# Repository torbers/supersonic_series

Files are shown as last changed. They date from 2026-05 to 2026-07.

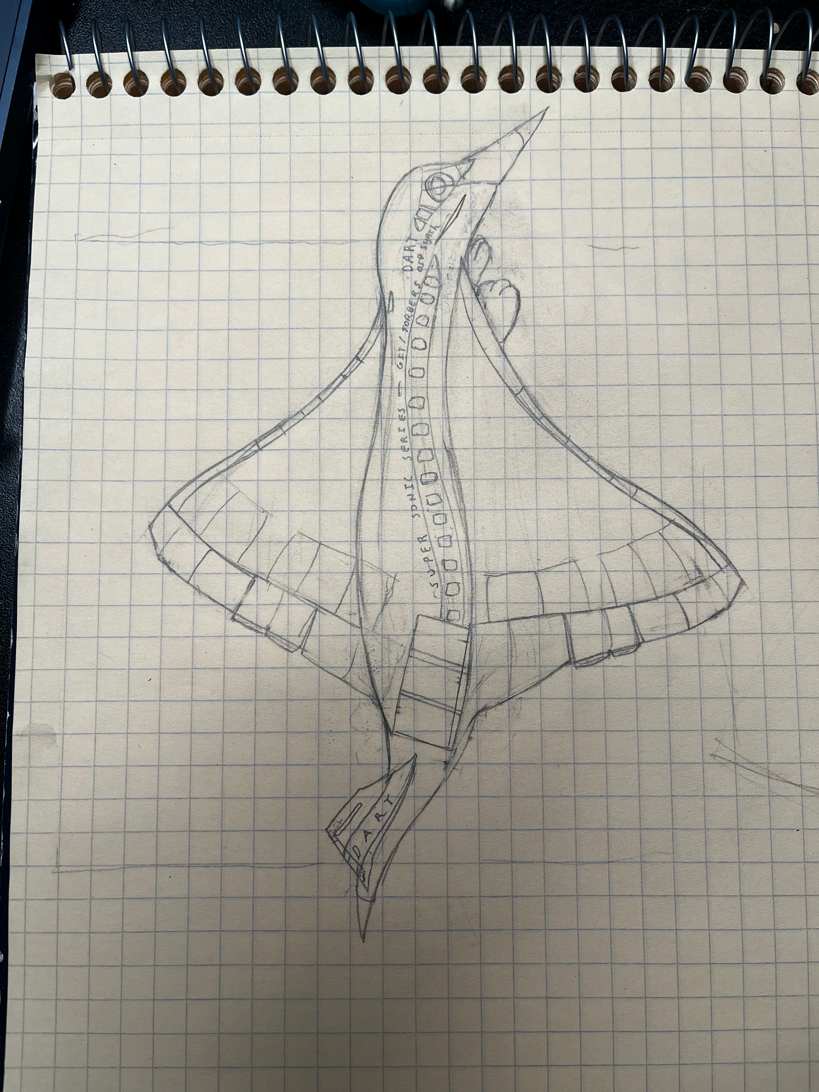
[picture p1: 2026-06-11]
delta/IMG_8657.png

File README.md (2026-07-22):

# Supersonic Series

Airplane dragon synthesizers

## Spike chord synthesizer
### Instruction card


### MIDI CC implementation
| Controller | Effect |
| --- | --- |
| 70 | Chord shape |
| 71 | Filter resonance |
| 72 | Amp envelope attack |
| 73 | Amp envelope release |
| 74 | Filter frequency |
| 75 | Delay time |
| 76 | Delay feedback |
| 77 | Detune |
| 78 | Oscillator bank spread |

### Building Arduino code
The Arduino IDE is the easiest, most portable way to compile and upload code to Spike. This section assumes no previous knowledge of the Arduino IDE in order to accommodate coders of all experience levels.
#### 1. Install Arduino IDE
Follow [this tutorial](https://docs.arduino.cc/software/ide-v2/tutorials/getting-started/ide-v2-downloading-and-installing/) to install the Arduino IDE 2 on your computer. The environment supports Windows, Mac, and Linux.

#### 2. Clone this repository
Use your preferred method to "clone" (download) this repository to your computer. I like the [github desktop app](https://desktop.github.com/download/), but you can also just download the whole thing as a .zip from the [main page](https://github.com/torbers/supersonic_series).

#### 3. Open the file
Once the IDE has installed, choose `File->Open` and navigate to and open `supersonic_series/spike copy/spike_v2_usb/spike_v2_usb.ino`. **Make sure** `spike_v2_usb.ino` and the other files stay in the `spike_v2_usb` folder or it won't open correctly!

#### 4. Install libraries
You will need to install 3 libraries from the built-in library manager (the book icon on the side of the Arduino window).
- **Mozzi** by Tim Barrass: This is our sound synthesis library
- **USB-MIDI** by lathoub: This library sends and recieves MIDI over USB
- **Adafruit_NeoPixel** by Adafruit: This library controls the built in LED

#### 5. Connect Spike
Connect Spike to your computer via the USB C port. **Make sure your cable is capable of data transmission or "sync," and isn't a power-only cable.**
It will appear in Arduino as `Arduino Zero (Native USB)` at the top of the screen. Make sure the text saying this is bold - if so, you're ready to upload.

#### 6. Compile and upload!
Press the arrow button at the top left of the screen to compile and upload the code.

---
## Licensing
All work is shared under [Creative Commons CC BY-SA 4.0](https://creativecommons.org/licenses/by-sa/4.0/): Anyone is free to share, remix, and commercialize it so long as they attribute the work and release it under this same license agreement. (Attribution text modified from [here](https://fullyautomatedrpg.com/licensing/).)

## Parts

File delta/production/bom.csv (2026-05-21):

Designator | Footprint | Quantity | Value | LCSC Part #
LED1, LED2, LED3 | LED-SEG-SMD_10P-L12.0-W7.3-P1.50-BL | 3 | GS3011CR-G | C22462656
U1 | VQFN-20-1EP_3x3mm_P0.4mm_EP1.7x1.7mm | 1 | ATtiny1616-M

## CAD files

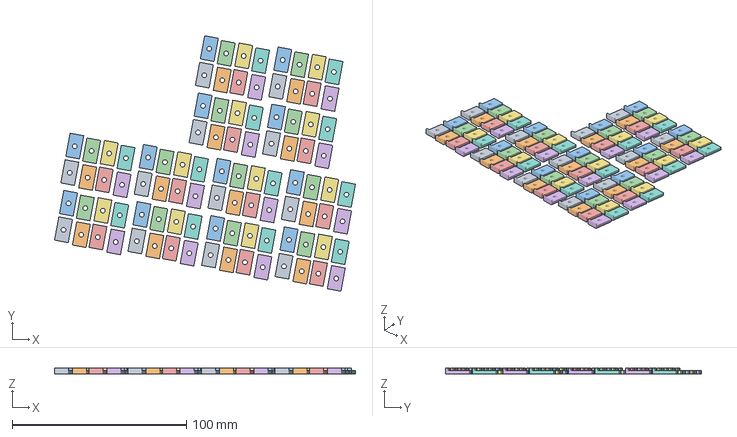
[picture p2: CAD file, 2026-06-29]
clamp2.3mf
172.6 x 146.5 x 3.60 mm
clamp2 x 96

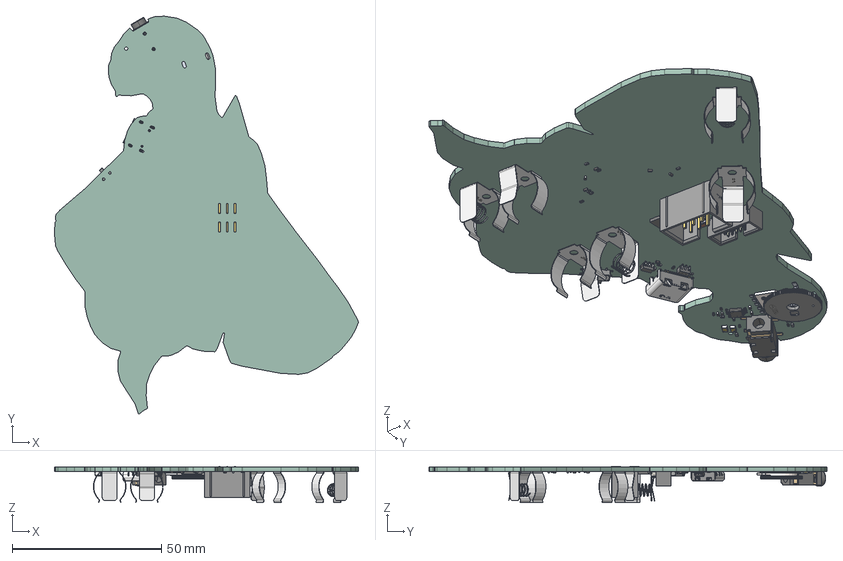
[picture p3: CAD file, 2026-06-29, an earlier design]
spike copy/creature/spike.step
102.0 x 133.4 x 12.1 mm
C_0402_1005Metric x 15
BAT-SMD_MY-AAA-19-J x 3
R_0402_1005Metric x 18
QFN-48-1EP_7x7mm_P0.5mm_EP5.15x5.15mm
IDC-SMD_10P-P1.27-3220-10-0300-00
BAT-SMD_MY-AAA-20-J x 3
SW-SMD_L3.9-W2.9-H2.0-LS4.8
DFN1006-2L-BI x 2
FC-135R_L3.2-W1.5
RES-SMD_RK10J11R0A0H
AUDIO-SMD_PJ-327A5JJ
SOT-23-5
MSOP-10_L3.0-W3.0-H1.1-LS5.0-P0.50
SW-SMD_3P-L6.6-W2.7-LS7.8-P1.50
SOT-23-6_L2.9-W1.6-H1.5-LS2.8-P0.95
USB-C_SMD-TYPE-C-31-M-12_1
C0805_L2.0-W1.3-H1.3 x 4
CONN-SMD_6P-P2.54_BH254VS
creature_PCB

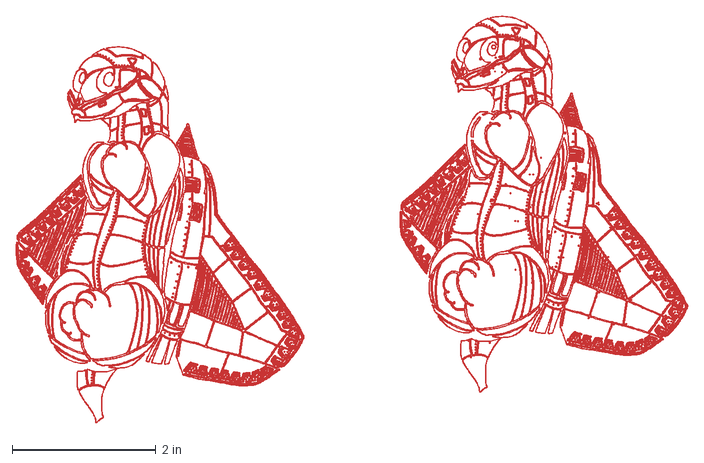
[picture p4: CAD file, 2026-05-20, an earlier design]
spike copy/creature/creature-Front.dxf
9.35 x 5.65 in

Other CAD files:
spike copy/creature/.step

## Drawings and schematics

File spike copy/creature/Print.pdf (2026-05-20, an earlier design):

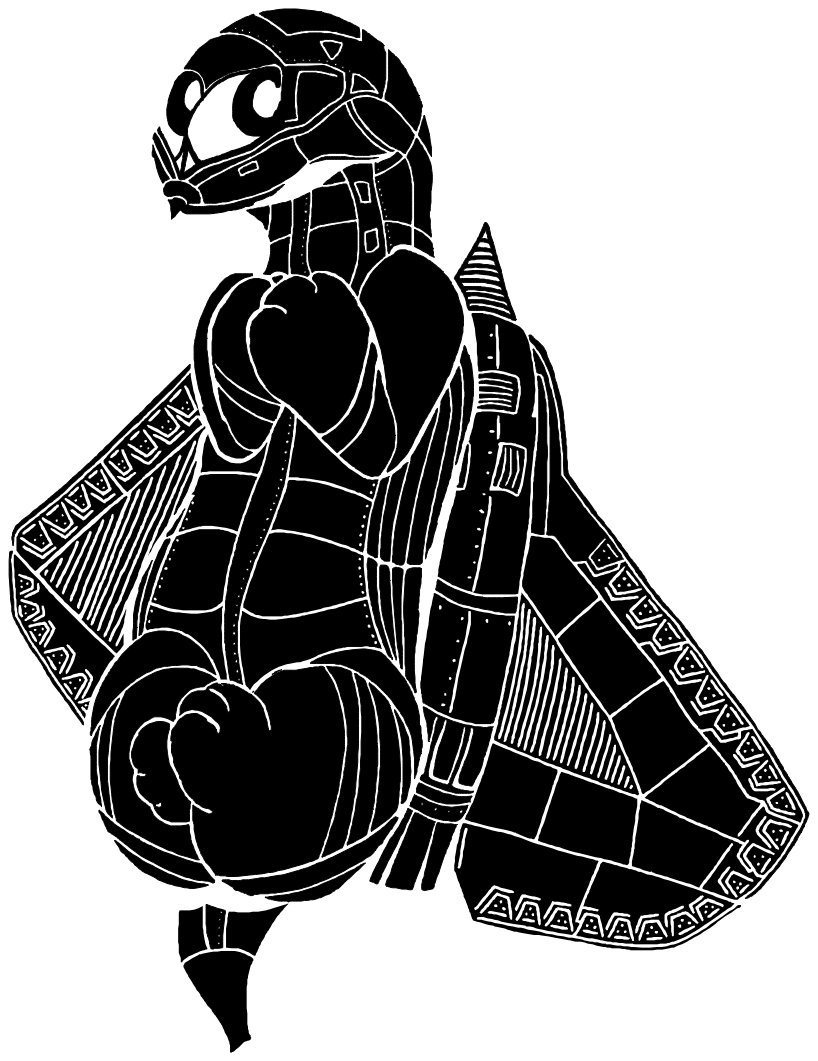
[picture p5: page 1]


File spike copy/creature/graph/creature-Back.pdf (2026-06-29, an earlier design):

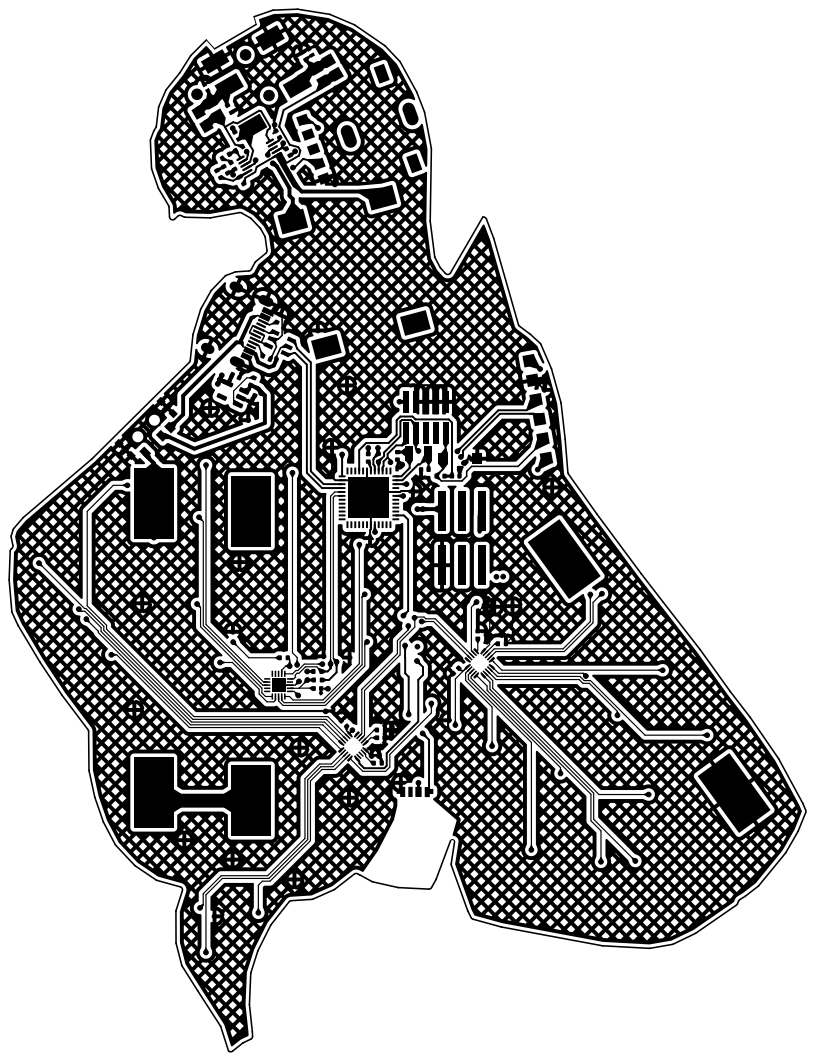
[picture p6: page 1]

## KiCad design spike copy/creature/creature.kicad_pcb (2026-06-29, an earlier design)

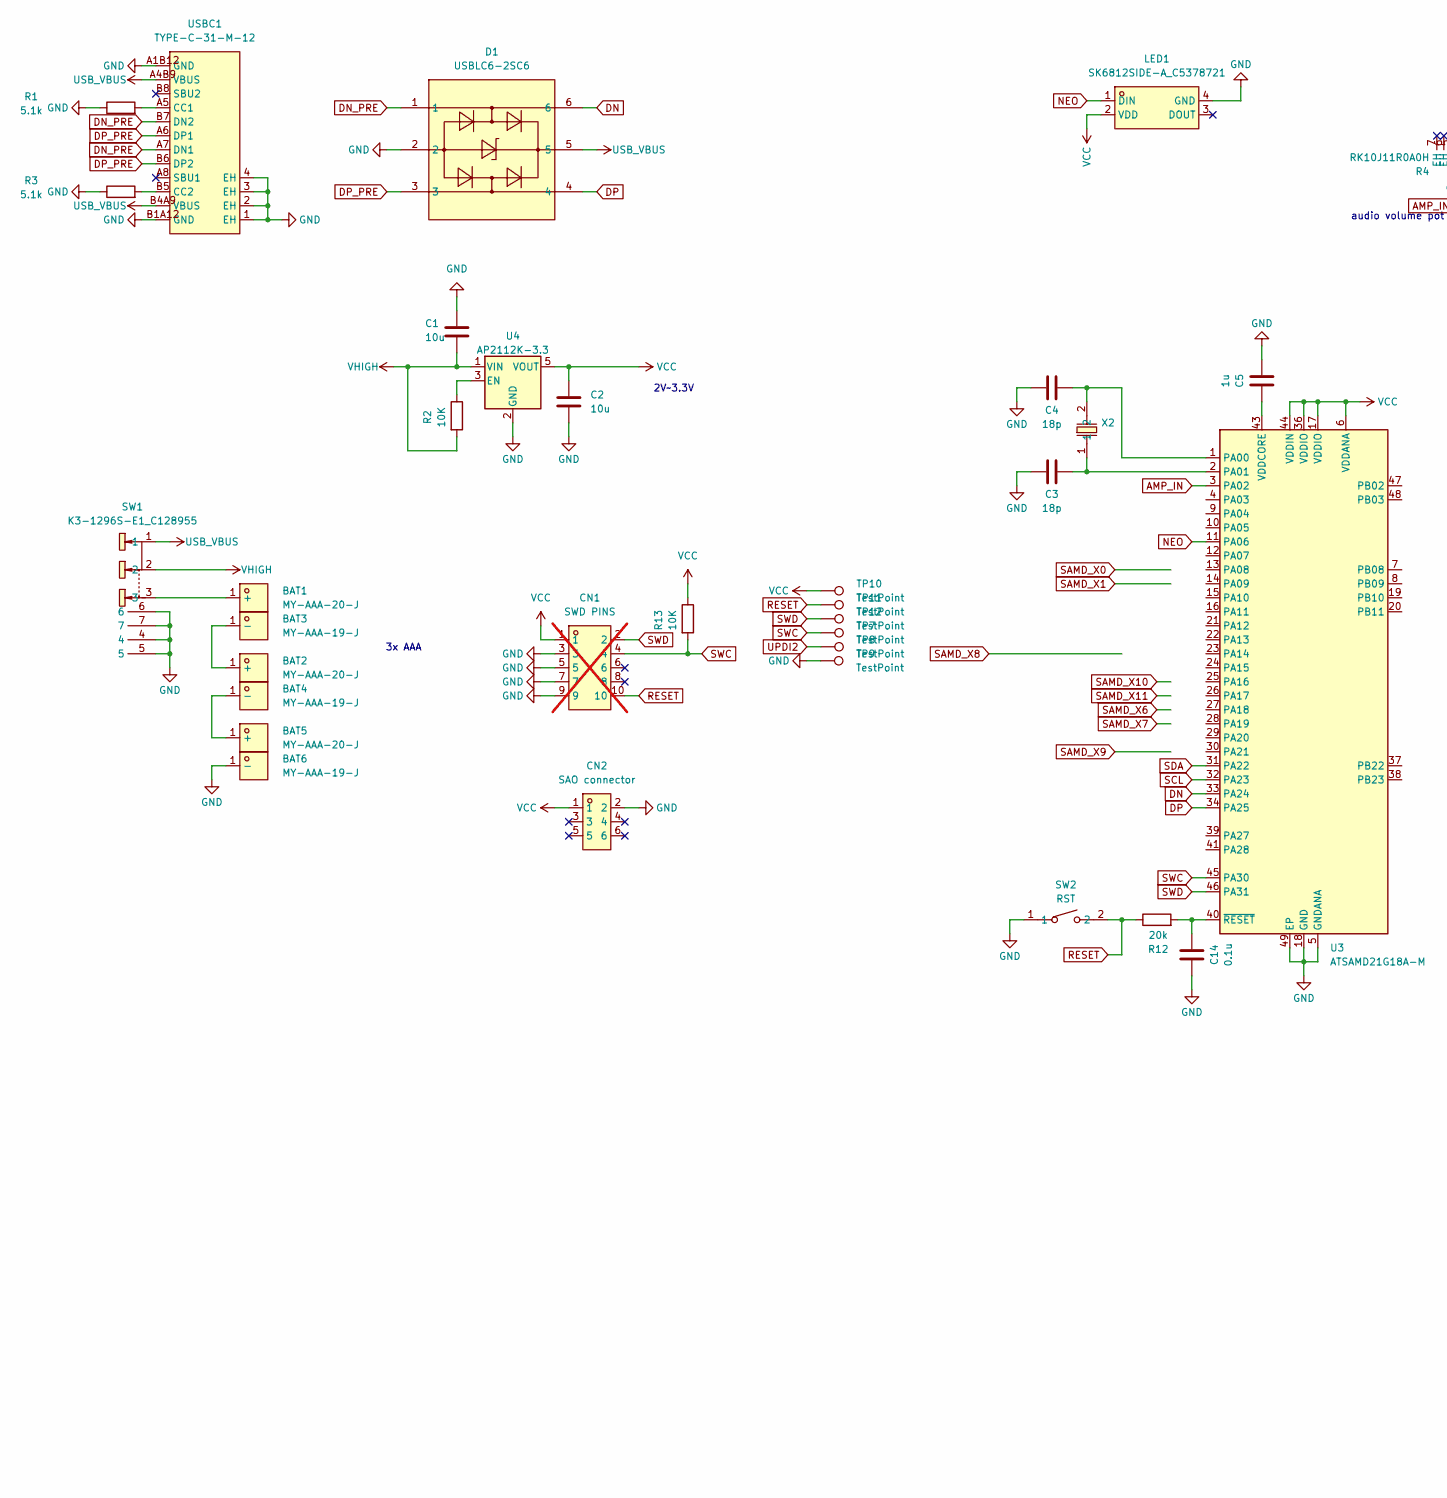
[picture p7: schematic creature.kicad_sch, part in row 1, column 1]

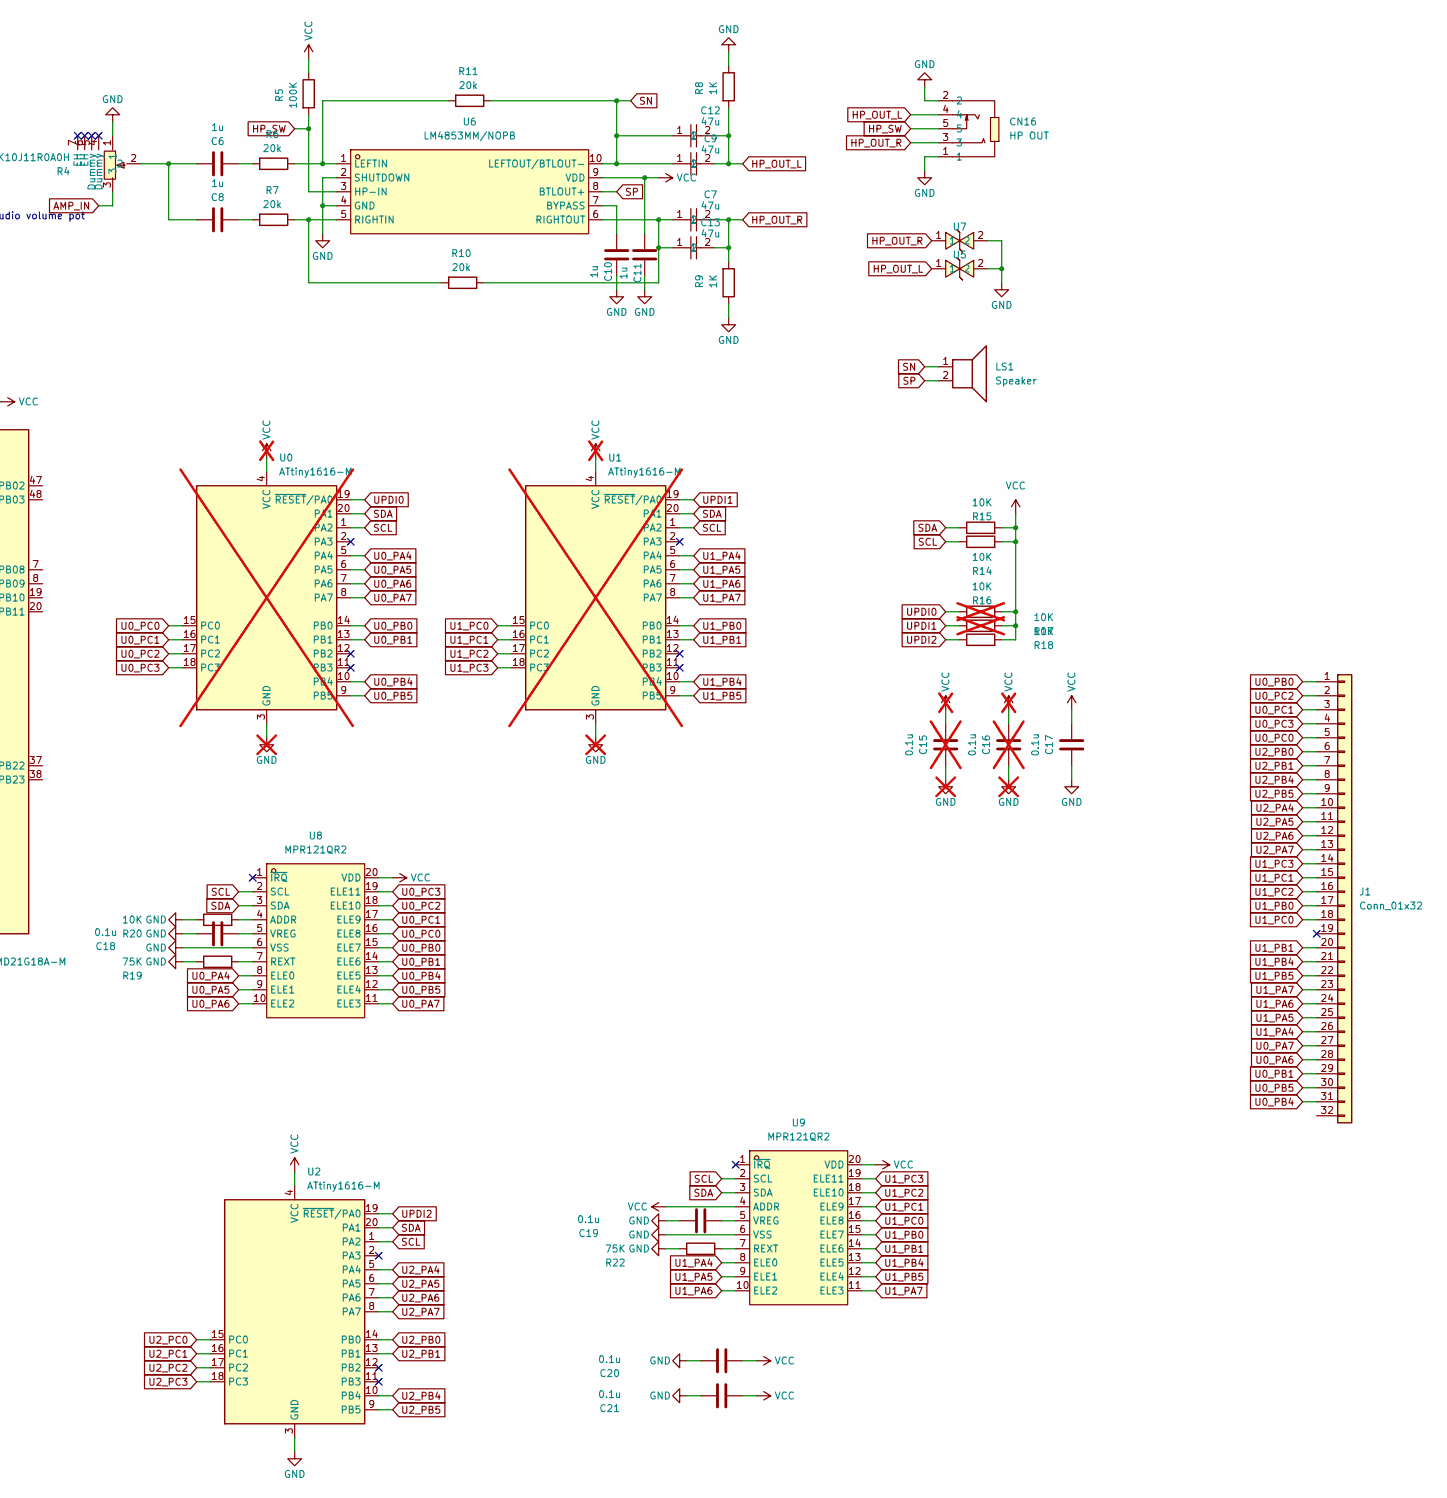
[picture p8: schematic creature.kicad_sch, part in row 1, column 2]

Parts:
BAT1, BAT2, BAT5: MY-AAA-20-J; BAT-SMD_MY-AAA-20-J; MPN MY-AAA-20-J; LCSC Part C6937107
BAT3, BAT4, BAT6: MY-AAA-19-J; BAT-SMD_MY-AAA-19-J; MPN MY-AAA-19-J; LCSC Part C6937104
C1, C2: 10u; C_0402_1005Metric
C3, C4: 18p; C_0402_1005Metric
C5, C6, C8, C10, C11: 1u; C_0402_1005Metric
C7, C9, C12, C13: 47u; C0805; MPN CL21A476MQYNNNE; LCSC Part C16780
C14, C17, C18, C19, C20, C21: 0.1u; C_0402_1005Metric
C15, C16: 0.1u; C_0402_1005Metric; not fitted
CN1: SWD PINS; IDC-SMD_10P-P1.27-3220-10-0300-00; MPN HX JN1.27-2x5 TP H4.9; LCSC Part C42372555; not fitted
CN2: SAO connector; CONN-SMD_6P-P2.54_BH254VS; MPN BH254VS-6P; LCSC Part C492445
CN16: HP OUT; AUDIO-SMD_PJ-327A5JJ; LCSC Part C668605
D1: USBLC6-2SC6; SOT-23-6_L2.9-W1.6-P0.95-LS2.8-BL; LCSC Part C7519
J1: Conn_01x32; spike_copper
LED1: SK6812SIDE-A_C5378721; LED-SMD_4P-L4.0-W1.6-L; LCSC Part C5378721
LS1: Speaker; FS1818MS0410-H5.9-R01
R1, R3: 5.1k; R_0402_1005Metric
R2, R13, R14, R15, R18, R20: 10K; R_0402_1005Metric
R4: RK10J11R0A0H; RES-SMD_RK10J11R0A0H; MPN RK10J11R0A0H; LCSC Part C470766
R5: 100K; R_0402_1005Metric
R6, R7, R10, R11, R12: 20k; R_0402_1005Metric
R8, R9: 1K; R_0402_1005Metric
R16, R17: 10K; R_0402_1005Metric; not fitted
R19, R22: 75K; R_0402_1005Metric
SW1: K3-1296S-E1_C128955; SW-TH_K3-1296S-E1; MPN K3-1296S-E1; LCSC Part C128955
SW2: RST; SW-SMD_L3.9-W3.0-P4.45; LCSC Part C720477
TP7, TP8, TP9, TP10, TP11, TP12: TestPoint; TestPoint_Pad_1.5x1.5mm
U0, U1: ATtiny1616-M; VQFN-20-1EP_3x3mm_P0.4mm_EP1.7x1.7mm; not fitted
U2: ATtiny1616-M; VQFN-20-1EP_3x3mm_P0.4mm_EP1.7x1.7mm
U3: ATSAMD21G18A-M; QFN-48-1EP_7x7mm_P0.5mm_EP5.15x5.15mm
U4: AP2112K-3.3; SOT-23-5
U5, U7: H3V3U10B; DFN1006-2L-BI; LCSC Part C20615782
U6: LM4853MM/NOPB; MSOP-10_L3.0-W3.0-P0.50-LS4.9-BL; MPN LM4853MM/NOPB; LCSC Part C2872995
U8, U9: MPR121QR2; QFN-20_L3.0-W3.0-P0.40-BL; LCSC Part C91322
USBC1: TYPE-C-31-M-12; USB-C_SMD-TYPE-C-31-M-12_1; LCSC Part C165948
X2: Q13FC1350000400; FC-135R_L3.2-W1.5; MPN Q13FC13500004; LCSC Part C32346

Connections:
AMP_IN: R4.3, U3.3 (PA02)
DN: D1.6, U3.33 (PA24)
DN_PRE: D1.1, USBC1.A7 (DN1), USBC1.B7 (DN2)
DP: D1.4, U3.34 (PA25)
DP_PRE: D1.3, USBC1.A6 (DP1), USBC1.B6 (DP2)
GND: BAT6.1 (-_1), C1.2, C2.2, C3.1, C4.1, C5.1, C10.2, C11.2, C14.1, C15.2, C16.2, C17.2, C18.2, C19.2, C20.2, C21.2, CN1.3, CN1.5, CN1.7, CN1.9, CN2.2, CN16.1, CN16.2, D1.2, LED1.4 (GND), R1.1, R3.1, R4.1, R8.1, R9.1, R19.1, R20.1, R22.1, SW1.4, SW1.5, SW1.6, SW1.7, SW2.1, TP9.1 (1_1), U0.3 (GND), U0.21 (GND), U1.3 (GND), U1.21 (GND), U2.3 (GND), U2.21 (GND), U3.5 (GNDANA), U3.18 (GND), U3.35 (GND), U3.42 (GND), U3.49 (EP), U4.2 (GND), U5.2, U6.2 (SHUTDOWN), U6.4 (GND), U7.2, U8.6 (VSS), U9.6 (VSS), USBC1.1 (EH), USBC1.2 (EH), USBC1.3 (EH), USBC1.4 (EH), USBC1.A1B12 (GND), USBC1.B1A12 (GND)
HP_OUT_L: C9.2, C12.2, CN16.4, R8.2, U5.1
HP_OUT_R: C7.2, C13.2, CN16.3, R9.2, U7.1
HP_SW: CN16.5, R5.2, U6.3 (HP-IN)
NEO: LED1.1 (DIN), U3.11 (PA06)
unnamed: BAT1.1 (+_1), SW1.3
unnamed: BAT2.1 (+_1), BAT3.1 (-_1)
unnamed: BAT4.1 (-_1), BAT5.1 (+_1)
unnamed: C6.1, R6.2
unnamed: C6.2, C8.2, R4.2
unnamed: C8.1, R7.2
unnamed: R16.1, U0.19 (~RESET/PA0)
unnamed: R17.1, U1.19 (~RESET/PA0)
unnamed: C4.2, U3.1 (PA00), X2.2
unnamed: C3.2, U3.2 (PA01), X2.1
unnamed: C5.2, U3.43 (VDDCORE)
unnamed: C14.2, R12.2, U3.40 (~RESET)
unnamed: R2.1, U4.3 (EN)
unnamed: C10.1, U6.7 (BYPASS)
unnamed: R6.1, R11.2, U6.1 (LEFTIN)
unnamed: R7.1, R10.2, U6.5 (RIGHTIN)
unnamed: C7.1, C13.1, R10.1, U6.6 (RIGHTOUT)
unnamed: R20.2, U8.4 (ADDR)
unnamed: R19.2, U8.7 (REXT)
unnamed: C18.1, U8.5 (VREG)
unnamed: R22.2, U9.7 (REXT)
unnamed: C19.1, U9.5 (VREG)
unnamed: R1.2, USBC1.A5 (CC1)
unnamed: R3.2, USBC1.B5 (CC2)
RESET: CN1.10, R12.1, SW2.2, TP11.1 (1_1)
SCL: R14.1, U0.1 (PA2), U1.1 (PA2), U2.1 (PA2), U3.32 (PA23), U8.2 (SCL), U9.2 (SCL)
SDA: R15.1, U0.20 (PA1), U1.20 (PA1), U2.20 (PA1), U3.31 (PA22), U8.3 (SDA), U9.3 (SDA)
SN: C9.1, C12.1, LS1.1, R11.1, U6.10 (LEFTOUT/BTLOUT-)
SP: LS1.2, U6.8 (BTLOUT+)
SWC: CN1.4, R13.2, TP7.1 (1_1), U3.45 (PA30)
SWD: CN1.2, TP12.1 (1_1), U3.46 (PA31)
U0_PA4: U0.5 (PA4), U8.8 (ELE0)
U0_PA5: U0.6 (PA5), U8.9 (ELE1)
U0_PA6: J1.28, U0.7 (PA6), U8.10 (ELE2)
U0_PA7: J1.27, U0.8 (PA7), U8.11 (ELE3)
U0_PB0: J1.1, U0.14 (PB0), U8.15 (ELE7)
U0_PB1: J1.29, U0.13 (PB1), U8.14 (ELE6)
U0_PB4: J1.31, U0.10 (PB4), U8.13 (ELE5)
U0_PB5: J1.30, U0.9 (PB5), U8.12 (ELE4)
U0_PC0: J1.5, U0.15 (PC0), U8.16 (ELE8)
U0_PC1: J1.3, U0.16 (PC1), U8.17 (ELE9)
U0_PC2: J1.2, U0.17 (PC2), U8.18 (ELE10)
U0_PC3: J1.4, U0.18 (PC3), U8.19 (ELE11)
U1_PA4: J1.26, U1.5 (PA4), U9.8 (ELE0)
U1_PA5: J1.25, U1.6 (PA5), U9.9 (ELE1)
U1_PA6: J1.24, U1.7 (PA6), U9.10 (ELE2)
U1_PA7: J1.23, U1.8 (PA7), U9.11 (ELE3)
U1_PB0: J1.17, U1.14 (PB0), U9.15 (ELE7)
U1_PB1: J1.20, U1.13 (PB1), U9.14 (ELE6)
U1_PB4: J1.21, U1.10 (PB4), U9.13 (ELE5)
U1_PB5: J1.22, U1.9 (PB5), U9.12 (ELE4)
U1_PC0: J1.18, U1.15 (PC0), U9.16 (ELE8)
U1_PC1: J1.15, U1.16 (PC1), U9.17 (ELE9)
U1_PC2: J1.16, U1.17 (PC2), U9.18 (ELE10)
U1_PC3: J1.14, U1.18 (PC3), U9.19 (ELE11)
U2_PA4: J1.10, U2.5 (PA4)
U2_PA5: J1.11, U2.6 (PA5)
U2_PA6: J1.12, U2.7 (PA6)
U2_PA7: J1.13, U2.8 (PA7)
U2_PB0: J1.6, U2.14 (PB0)
U2_PB1: J1.7, U2.13 (PB1)
U2_PB4: J1.8, U2.10 (PB4)
U2_PB5: J1.9, U2.9 (PB5)
U2_PC0: U2.15 (PC0)
U2_PC1: U2.16 (PC1)
U2_PC2: U2.17 (PC2)
U2_PC3: U2.18 (PC3)
UPDI2: R18.1, TP8.1 (1_1), U2.19 (~RESET/PA0)
USB_VBUS: D1.5, SW1.1, USBC1.A4B9 (VBUS), USBC1.B4A9 (VBUS)
VCC: C2.1, C11.1, C15.1, C16.1, C17.1, C20.1, C21.1, CN1.1, CN2.1, LED1.2 (VDD), R5.1, R13.1, R14.2, R15.2, R16.2, R17.2, R18.2, TP10.1 (1_1), U0.4 (VCC), U1.4 (VCC), U2.4 (VCC), U3.6 (VDDANA), U3.17 (VDDIO), U3.36 (VDDIO), U3.44 (VDDIN), U4.5 (VOUT), U6.9 (VDD), U8.20 (VDD), U9.4 (ADDR), U9.20 (VDD)
VHIGH: C1.1, R2.2, SW1.2, U4.1 (VIN)

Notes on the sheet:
3x AAA
audio volume pot
2V~3.3V

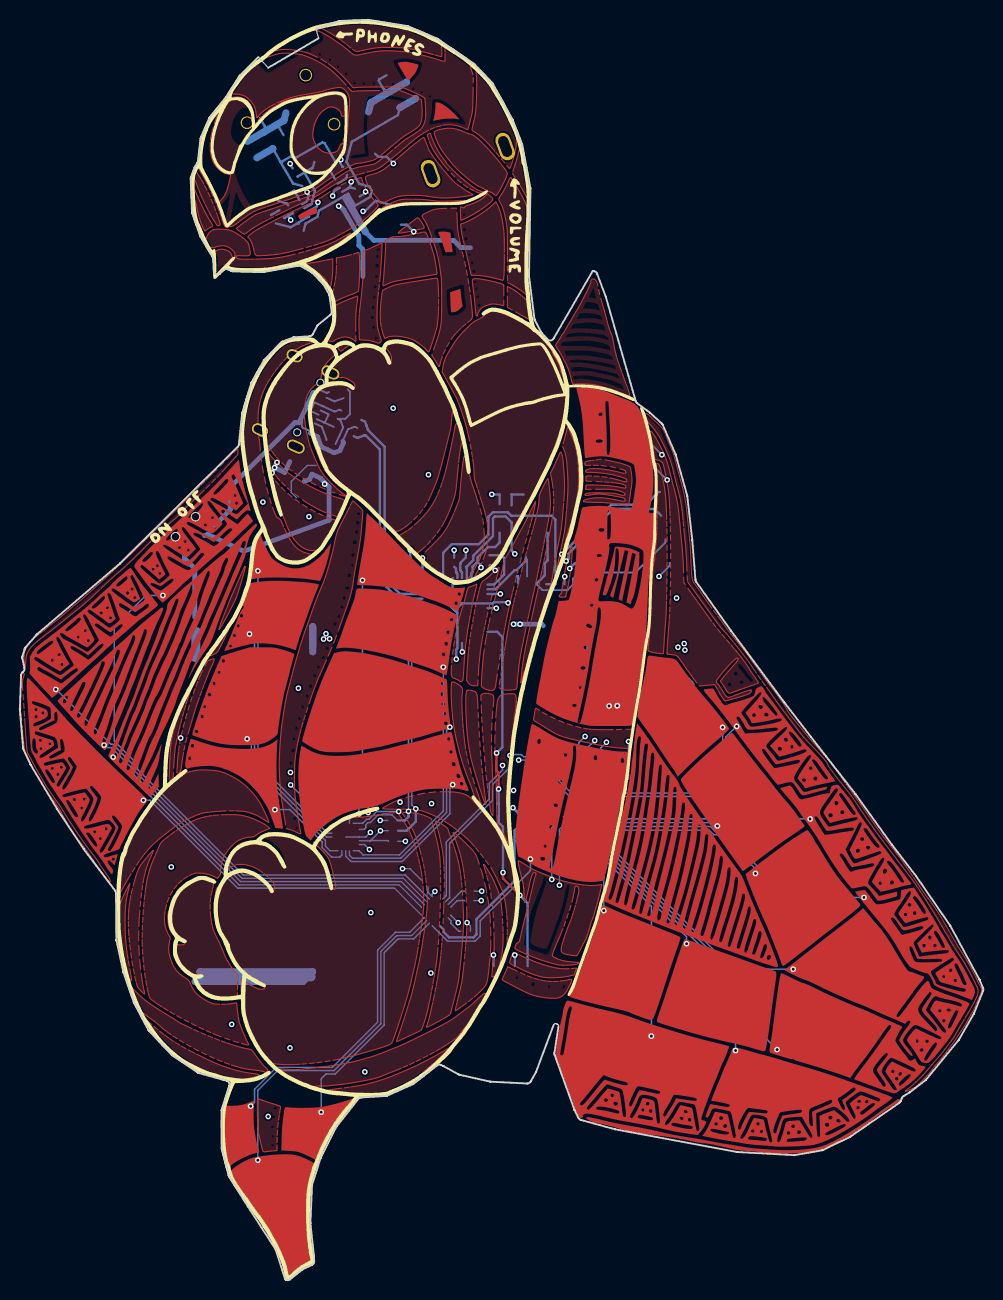
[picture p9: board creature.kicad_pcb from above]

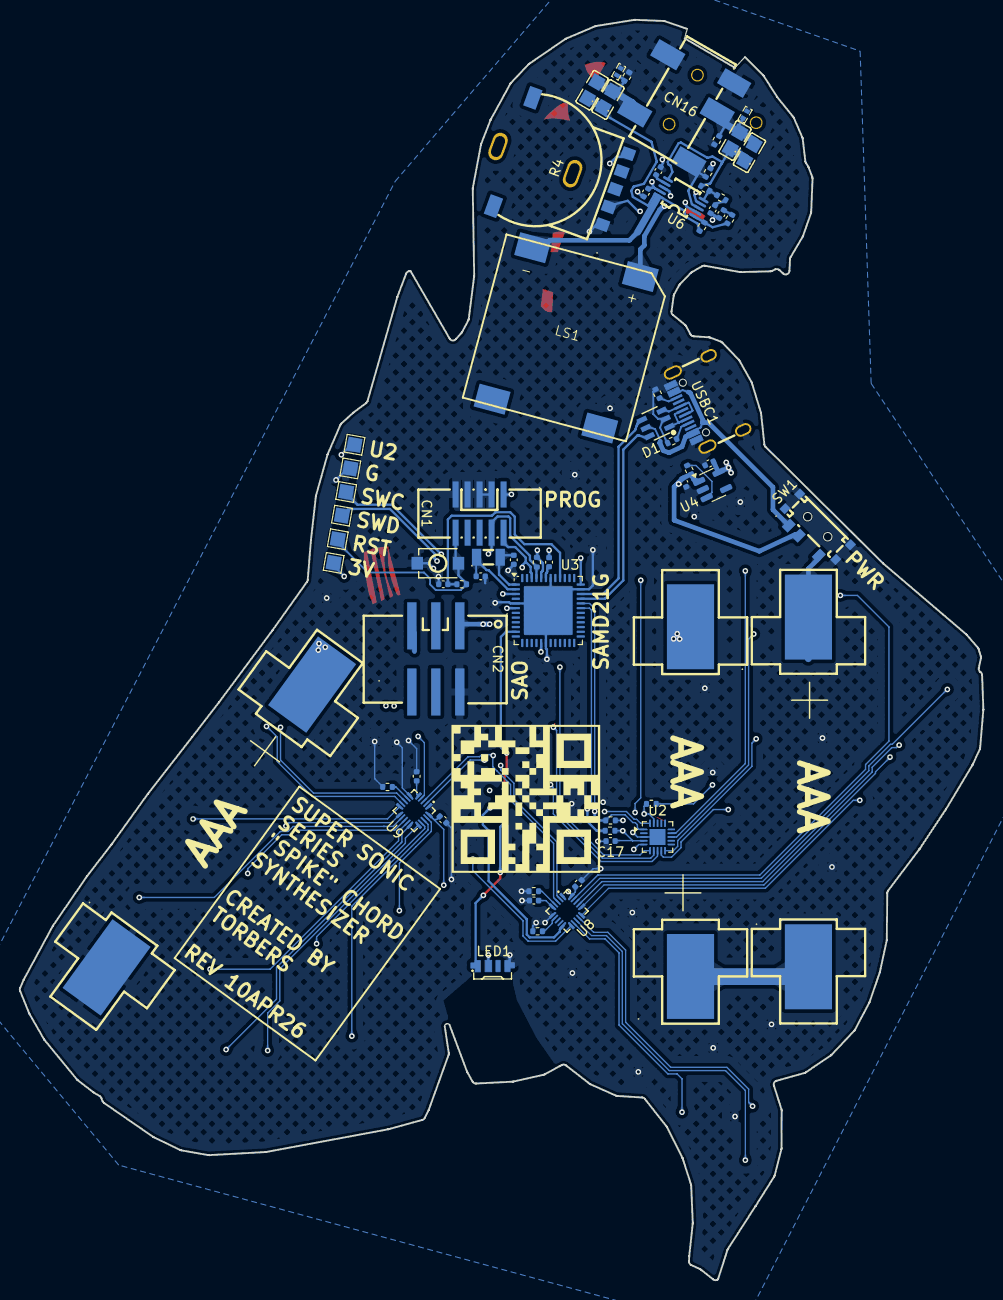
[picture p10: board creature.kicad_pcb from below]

Board: 4 copper layers, 102.0 x 133.4 mm, 69 parts (68 on the bottom side), 73 nets.

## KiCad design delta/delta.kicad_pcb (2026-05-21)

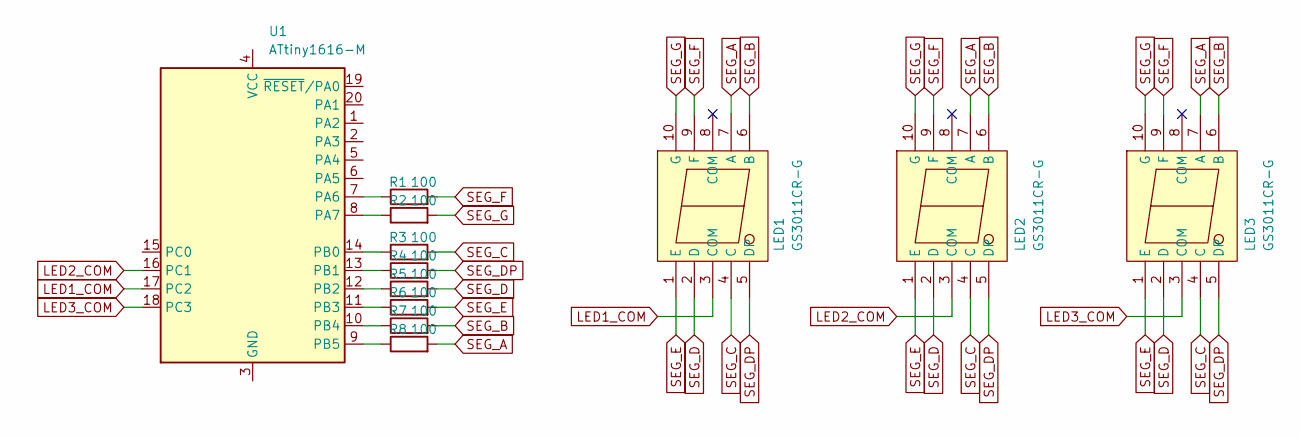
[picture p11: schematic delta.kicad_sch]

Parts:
LED1, LED2, LED3: GS3011CR-G; LED-SEG-SMD_10P-L12.0-W7.3-P1.50-BL; MPN GS3011CR-G; LCSC Part C22462656
R1, R2, R3, R4, R5, R6, R7, R8: 100; R_0402_1005Metric
U1: ATtiny1616-M; VQFN-20-1EP_3x3mm_P0.4mm_EP1.7x1.7mm

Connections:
LED1_COM: LED1.3 (COM), U1.17 (PC2)
LED2_COM: LED2.3 (COM), U1.16 (PC1)
LED3_COM: LED3.3 (COM), U1.18 (PC3)
unnamed: U1.3 (GND), U1.21 (GND)
unnamed: R1.1, U1.7 (PA6)
unnamed: R2.1, U1.8 (PA7)
unnamed: R3.1, U1.14 (PB0)
unnamed: R4.1, U1.13 (PB1)
unnamed: R5.1, U1.12 (PB2)
unnamed: R6.1, U1.11 (PB3)
unnamed: R7.1, U1.10 (PB4)
unnamed: R8.1, U1.9 (PB5)
SEG_A: LED1.7 (A), LED2.7 (A), LED3.7 (A), R8.2
SEG_B: LED1.6 (B), LED2.6 (B), LED3.6 (B), R7.2
SEG_C: LED1.4 (C), LED2.4 (C), LED3.4 (C), R3.2
SEG_D: LED1.2 (D), LED2.2 (D), LED3.2 (D), R5.2
SEG_DP: LED1.5 (DP), LED2.5 (DP), LED3.5 (DP), R4.2
SEG_E: LED1.1 (E), LED2.1 (E), LED3.1 (E), R6.2
SEG_F: LED1.9 (F), LED2.9 (F), LED3.9 (F), R1.2
SEG_G: LED1.10 (G), LED2.10 (G), LED3.10 (G), R2.2

Board: 4 copper layers, 12 parts (9 on the bottom side), 20 nets, no tracks yet.

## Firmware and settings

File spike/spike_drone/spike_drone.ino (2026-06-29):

#define MOZZI_CONTROL_RATE 256
#define MOZZI_AUDIO_RATE 16384

#include <Mozzi.h>
#include <Oscil.h>
#include <tables/saw512_int8.h>
#include <ResonantFilter.h>
#include <mozzi_midi.h> // for mtof
#include <AudioDelayFeedback.h>

#include <Arduino.h>
#include <Adafruit_TinyUSB.h>
#include <MIDI.h>
#include <Wire.h>
#include <Adafruit_NeoPixel.h>



#define NEO_PIN 8

//#include "Slider.h"

// Settings macros
// Filter
#define LOWPASS 0x00
#define BANDPASS 0x01
#define HIGHPASS 0x02
#define LOWPASS_TRACK 0x03
#define BANDPASS_TRACK 0x04
#define HIGHPASS_TRACK 0x05
#define FILTER_MODES_COUNT 0x06

#define A 0b001
#define B 0b100
#define C 0b010

#define PLUS 0b10
#define MINUS 0b01

#define MAX_OCTAVE 10


//Adafruit_USBD_MIDI usb_midi;
//MIDI_CREATE_INSTANCE(Adafruit_USBD_MIDI, usb_midi, MIDI);

Adafruit_NeoPixel pixel(1, NEO_PIN, NEO_GRB + NEO_KHZ800);


// Audio objects

Oscil <SAW512_NUM_CELLS, MOZZI_AUDIO_RATE> saw0(SAW512_DATA);
Oscil <SAW512_NUM_CELLS, MOZZI_AUDIO_RATE> saw1(SAW512_DATA);
Oscil <SAW512_NUM_CELLS, MOZZI_AUDIO_RATE> saw2(SAW512_DATA);
Oscil <SAW512_NUM_CELLS, MOZZI_AUDIO_RATE> saw3(SAW512_DATA);
Oscil <SAW512_NUM_CELLS, MOZZI_AUDIO_RATE> saw4(SAW512_DATA);
Oscil <SAW512_NUM_CELLS, MOZZI_AUDIO_RATE> saw5(SAW512_DATA);
Oscil <SAW512_NUM_CELLS, MOZZI_AUDIO_RATE> saw6(SAW512_DATA);
Oscil <SAW512_NUM_CELLS, MOZZI_AUDIO_RATE> saw7(SAW512_DATA);

MultiResonantFilter<uint8_t> mf0;
MultiResonantFilter<uint8_t> mf1;

AudioDelayFeedback <0x800> aDel;



// Global vars

uint16_t chords[] = {
  (0 << 0) + (7 << 4) + (12 << 8) + (12 << 12), // Base note
  (0 << 0) + (0 << 4) + (12 << 8) + (12 << 12),
  (0 << 0) + (0 << 4) + (12 << 8) + (12 << 12),
  (0 << 0) + (0 << 4) + (12 << 8) + (12 << 12),
  (0 << 0) + (0 << 4) + (12 << 8) + (12 << 12),
  (0 << 0) + (0 << 4) + (12 << 8) + (12 << 12),
  (0 << 0) + (0 << 4) + (12 << 8) + (12 << 12),
  (0 << 0) + (0 << 4) + (12 << 8) + (12 << 12),
  (0 << 0) + (0 << 4) + (12 << 8) + (12 << 12)
};


// Sliders
// Real-time position
uint8_t l_position = 0xFF;
uint8_t r_position = 0xFF;

bool l_touched = false;
bool r_touched = false;

bool plus_touched_new =  false;
bool minus_touched_new = false;

bool plus_touched_prev =  false;
bool minus_touched_prev = false;

// Control pads
// Actual true/false of all control pads
uint8_t chord_pad_bin = 0b00000000;
// 0 0 0 N W E S C

uint16_t note_pad_bin = 0b0000000000000000;
// 0 0 0 0 VII VI# VI V# V IV# IV III II# II I# I

// +- pad and ABC
uint8_t set_pad_bin = 0b00000000;
// 0 0 0 + - B C A


// The most recent control pad or direction that has been touched; 0xFF = none touched at the moment
//uint8_t chord_pad = 0xFF;  // this has 5 pads but 9 directions; enumerated 0-8
//uint8_t note_pad =  0xFF;

//uint8_t chord_number = 0x00;
//uint8_t note_pad =  0xFF;

uint16_t chord = chords[0];
uint8_t note;

// Transposition
uint8_t octave_transpose = 2;
uint8_t note_transpose =   0;

int8_t osc_transpose = 24;


// Corresponding values' positions
// default
uint8_t bend_position =    0x80;
uint8_t detune_position =  0x00;

// A set
uint8_t phase_rate =  0x00;
uint8_t phase_depth = 0x00;

// B setczczc
uint8_t filter_position = 0x80;
uint8_t filter_res =      0x00;
// +- pads: filter type
uint8_t filter_type =  LOWPASS;

// C set

// +- pads: note transposition



bool note_chord_spread_change = true;
bool filter_change = true;
bool delay_change = true;




// the delay time, measured in samples, updated in updateControl, and used in updateAudio
Q16n16 del_samps = 0x800;
uint8_t del_fb = 5;

float spread = 0.1;

bool drive = 0;





void updateParameters() {
  switch ((0b00011000 & set_pad_bin) >> 3){ // Update plus minus pads
    case PLUS:
      if (plus_touched_prev) {plus_touched_new = 0;}
      else {plus_touched_new = 1; plus_touched_prev = 1;}
      break;

    case MINUS:
      if (minus_touched_prev) {minus_touched_new = 0;}
      else {minus_touched_new = 1; minus_touched_prev = 1;}
      break;
    
    default:
      minus_touched_prev = 0;
      plus_touched_prev = 0;

      minus_touched_new = 0;
      plus_touched_new = 0;
  }


  switch (0b00000111 & set_pad_bin) { // ABC pads settings
    case A: // Set mode A
      if (l_touched) {phase_rate = l_position;}
      if (r_touched) {phase_depth = r_position;}
      break;

    case B: // Set mode B
      if (l_touched) {filter_position = l_position;}
      if (r_touched) {filter_res = r_position;}

      if (plus_touched_new) {filter_type++;}
      if (minus_touched_new) {filter_type--;}
      if (filter_type >= FILTER_MODES_COUNT) {filter_type = 0;}
      break;

    case C: // Set mode C

      if (plus_touched_new) {note_transpose++;}
      if (minus_touched_new) {note_transpose--;}
      if (note_transpose >= 12) {note_transpose = 0;}
      break;

    default: // No set mode selected; default behavoir
      if (l_touched) {bend_position = l_position;} // Pitchbend
      else {bend_position = 0x80;} // Snap back to center
      if (r_touched) {
        detune_position = r_position;
        spread = (float) detune_position * (octave_transpose + (note_transpose / 12)) / 255;
      }

      if (plus_touched_new) {octave_transpose++;}
      if (minus_touched_new) {octave_transpose--;}
      if (octave_transpose >= MAX_OCTAVE) {octave_transpose = 0;}
  }

  switch (chord_pad_bin) { // Set chord shape to be played
    case 0b00000000:
      break;

    case 0b00000001:
      chord = chords[0];
      break;
  }
}


void setup() {
  // Hardware setup
  // MIDI

  delay(500);
/*
  if (!TinyUSBDevice.isInitialized()) {
    TinyUSBDevice.begin(0);
  }

  if (TinyUSBDevice.mounted()) {
    TinyUSBDevice.detach();
    delay(10);
    TinyUSBDevice.attach();
  }


  MIDI.begin(MIDI_CHANNEL_OMNI);

  usb_midi.setStringDescriptor("TinyUSB MIDI");


  MIDI.setHandleNoteOn(handleNoteOn);
  MIDI.setHandleNoteOff(handleNoteOff);
*/
  Serial.begin(115200);
  while (!Serial) {
    ;  // wait for serial port to connect. Needed for native USB port only
  }

  Serial.println("Ok");

  //Wire.begin();

  // Touch

  //sliderL.begin();
  //sliderR.begin();

  delay(500);

  Serial.println("Wire");

  Wire.begin();
  Wire.setClock(100000);

  pixel.begin();
  pixel.setPixelColor(0, pixel.Color(0, 150, 0));
  pixel.show();
  // Audio setup

  startMozzi(); // :)

}

void loop(){
  audioHook(); // required here
}

void updateControl(){
  // put changing controls in here

  // MIDI
 // MIDI.read();


  // Controls
  //int slider_read_L = sliderL.readSlider();
  //int slider_read_R = sliderR.readSlider();

  //bool l_touched = false;
  //bool r_touched = false;

  //if (slider_read_L != -1) {l_position = slider_read_L; l_touched = true; Serial.println(l_position);}
  //if (slider_read_R != -1) {r_position = slider_read_R; r_touched = true; Serial.println(r_position);}


  //Serial.println("Getting wire data 0");
  Wire.requestFrom(0x61, 24);
  while (Wire.available()) {
    //Serial.printf("%02x", (uint8_t)Wire.read());
    uint16_t val = Wire.read() << 8;
    val += Wire.read();
    //Serial.printf("%07d", static_cast<int16_t>(val));
    Serial.print(' ');
  }
  //Serial.println();

  //Serial.println("Getting wire data 1");
  Wire.requestFrom(0x60, 12);
  while (Wire.available()) {
    //Serial.printf("%08b", (uint8_t)Wire.read());
    //Serial.print(' ');
  }
  //Serial.println();

  //Serial.println("Getting wire data 2");
  Wire.requestFrom(0x62, 4);
  while (Wire.available()) {
    //Serial.printf("%02x", (uint8_t)Wire.read());
    //Serial.print(' ');
  }
  //Serial.println();
  Serial.println("next");

  
  //updateParameters();

  // Apply changes

  if (note_chord_spread_change) {
    saw0.setFreq(mtof((chord & 0b0000000000001111) + octave_transpose * 12 + note_transpose + note) - spread * 3);
    saw1.setFreq(mtof(((chord & 0b0000000011110000) >> 4) + octave_transpose * 12 + note_transpose + note) - spread);
    saw2.setFreq(mtof(((chord & 0b0000111100000000) >> 8) + octave_transpose * 12 + note_transpose + note) + spread);
    saw3.setFreq(mtof(((chord & 0b1111000000000000) >> 12) + octave_transpose * 12 + note_transpose + note) + spread * 3);

    saw4.setFreq(mtof((chord & 0b0000000000001111) + octave_transpose * 12 + note_transpose + note + osc_transpose) - spread * 3);
    saw5.setFreq(mtof(((chord & 0b0000000011110000) >> 4) + octave_transpose * 12 + note_transpose + note + osc_transpose) - spread);
    saw6.setFreq(mtof(((chord & 0b0000111100000000) >> 8) + octave_transpose * 12 + note_transpose + note + osc_transpose) + spread);
    saw7.setFreq(mtof(((chord & 0b1111000000000000) >> 12) + octave_transpose * 12 + note_transpose + note + osc_transpose) + spread * 3);

    note_chord_spread_change = false;
  }

  if (filter_change) {
    mf0.setCutoffFreqAndResonance(r_position, 0x40);
    mf1.setCutoffFreqAndResonance(r_position, 0x40);
    //filter_change = false;
  }

  if (delay_change) {
    aDel.setFeedbackLevel(del_fb);
    delay_change = false;
  }
  

}


AudioOutput updateAudio(){
  int amix1 = (saw0.next() + saw1.next()) >> !drive;
  int amix2 = (saw2.next() + saw3.next()) >> !drive;
  int amix12 = (amix1 + amix2) >> 1;

  mf0.next(amix12);

  int amix3 = (saw4.next() + saw5.next()) >> !drive;
  int amix4 = (saw6.next() + saw7.next()) >> !drive;
  int amix34 = (amix1 + amix2) >> 1;

  mf1.next(amix34);

  //mf0.next((saw0.next() + saw1.next() + saw2.next() + saw3.next())/4);

  //mf1.next((saw4.next() + saw5.next() + saw6.next() + saw7.next())/4);

  int bank1 = mf0.low();
  int bank2 = mf1.low();

  int filt_sum = (bank1 + bank2) >> 1;

  int del_out = aDel.next(filt_sum, del_samps);

  int mixed = (del_out + filt_sum << 1) >> 1;
  
  return MonoOutput::fromAlmostNBit(10, mixed);
}

/*

void handleNoteOn(byte channel, byte pitch, byte velocity) {
  // Log when a note is pressed.

  note = pitch % 12;
  octave_transpose = (uint8_t) pitch / 12;

  note_chord_spread_change = true;
}

void handleNoteOff(byte channel, byte pitch, byte velocity) {
  // Log when a note is released.
}

*/

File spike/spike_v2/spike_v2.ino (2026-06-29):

#include "Spike.h"

#include <Mozzi.h>
#include <Oscil.h>
#include <tables/saw512_int8.h>
#include <ResonantFilter.h>
#include <mozzi_midi.h> // for mtof
#include <AudioDelayFeedback.h>
#include <ADSR.h>


#include <Adafruit_NeoPixel.h>

#define MOZZI_CONTROL_RATE 256
//#define MOZZI_AUDIO_RATE 16384

Spike spike;
Adafruit_NeoPixel pixel(1, 8, NEO_GRB + NEO_KHZ800);



uint8_t note = 0;
uint8_t base = 36;
int8_t oplus = 12;



uint8_t chords[9][4] = {
  {0, 12, 0, 12}, // Center
  {0, 4, 7, 12},  // n maj
  {0, 5, 7, 12},  // nw sus4
  {0, 3, 7, 12},  // w min
  {0, 3, 7, 10},  // we min7
  {0, 4, 7, 11},  // s dim
  {0, 2, 7, 12},  // se sus2
  {0, 7, 7, 12},  // e 5th
  {0, 4, 7, 11}   // ne maj7
};



// Audio objects
// Oscillators
Oscil <SAW512_NUM_CELLS, MOZZI_AUDIO_RATE> saw0(SAW512_DATA);
Oscil <SAW512_NUM_CELLS, MOZZI_AUDIO_RATE> saw1(SAW512_DATA);
Oscil <SAW512_NUM_CELLS, MOZZI_AUDIO_RATE> saw2(SAW512_DATA);
Oscil <SAW512_NUM_CELLS, MOZZI_AUDIO_RATE> saw3(SAW512_DATA);
Oscil <SAW512_NUM_CELLS, MOZZI_AUDIO_RATE> saw4(SAW512_DATA);
Oscil <SAW512_NUM_CELLS, MOZZI_AUDIO_RATE> saw5(SAW512_DATA);
Oscil <SAW512_NUM_CELLS, MOZZI_AUDIO_RATE> saw6(SAW512_DATA);
Oscil <SAW512_NUM_CELLS, MOZZI_AUDIO_RATE> saw7(SAW512_DATA);
float spread = 0.001;

// Filter
MultiResonantFilter<uint8_t> mf0;
MultiResonantFilter<uint8_t> mf1;
uint8_t filter_position = 0x80;
uint8_t filter_res =      0x00;
uint8_t filter_type =  LOWPASS;


// Delay effect
AudioDelayFeedback <0x0800> aDel;
Q16n16 del_samps = 0x00000001;
uint8_t del_fb = 0x00;

// Amp effects
bool drive = 0;

// envelope
ADSR <MOZZI_CONTROL_RATE, MOZZI_CONTROL_RATE> envelope;
unsigned int attack = 0;
unsigned int decay = 0;
unsigned int sustain = 1000000;
unsigned int release_ms = 255;
bool do_envelope = true;
uint8_t gain = 0;


uint8_t mode = 0;

uint8_t chord_index = 0;


void setMode() {
  if      ((!spike.pad_a) && (!spike.pad_b) && (!spike.pad_c)) {mode = 0; pixel.setPixelColor(0, pixel.Color(  0,   0, 255));}
  else if (( spike.pad_a) && (!spike.pad_b) && (!spike.pad_c)) {mode = 1; pixel.setPixelColor(0, pixel.Color(200,   0,   0));} // A
  else if (( spike.pad_a) && ( spike.pad_b) && (!spike.pad_c)) {mode = 2; pixel.setPixelColor(0, pixel.Color(150, 150,   0));}
  else if ((!spike.pad_a) && ( spike.pad_b) && (!spike.pad_c)) {mode = 3; pixel.setPixelColor(0, pixel.Color(  0, 200,   0));} // B
  else if ((!spike.pad_a) && ( spike.pad_b) && ( spike.pad_c)) {mode = 4; pixel.setPixelColor(0, pixel.Color(  0, 120, 250));}
  else if ((!spike.pad_a) && (!spike.pad_b) && ( spike.pad_c)) {mode = 5; pixel.setPixelColor(0, pixel.Color(  50,   50, 250));} // C
  else if (( spike.pad_a) && (!spike.pad_b) && ( spike.pad_c)) {mode = 6; pixel.setPixelColor(0, pixel.Color(150,   0, 250));}

  pixel.show();
}

void setChord() {
  if      ((!spike.pad_n) && (!spike.pad_w) && (!spike.pad_s) && (!spike.pad_e)) {chord_index = 0;} // none

  else if (( spike.pad_n) && (!spike.pad_w) && (!spike.pad_s) && (!spike.pad_e)) {chord_index = 1;} // n maj
  else if (( spike.pad_n) && ( spike.pad_w) && (!spike.pad_s) && (!spike.pad_e)) {chord_index = 2;} // nw sus4
  else if ((!spike.pad_n) && ( spike.pad_w) && (!spike.pad_s) && (!spike.pad_e)) {chord_index = 3;} // w min
  else if ((!spike.pad_n) && ( spike.pad_w) && (!spike.pad_s) && ( spike.pad_e)) {chord_index = 4;} // we min7
  else if ((!spike.pad_n) && (!spike.pad_w) && ( spike.pad_s) && (!spike.pad_e)) {chord_index = 5;} // s dim
  else if ((!spike.pad_n) && (!spike.pad_w) && ( spike.pad_s) && ( spike.pad_e)) {chord_index = 6;} // se sus2
  else if ((!spike.pad_n) && (!spike.pad_w) && (!spike.pad_s) && ( spike.pad_e)) {chord_index = 7;} // e 5th
  else if (( spike.pad_n) && (!spike.pad_w) && (!spike.pad_s) && ( spike.pad_e)) {chord_index = 8;} // ne maj7

}


void doSliderChanges(){
  if (spike.slider_touched_l) {
    pixel.setPixelColor(0, pixel.Color(spike.slider_pos_l / 2 + 128, 0, 255));
  }
  else if (spike.slider_touched_r) {
    pixel.setPixelColor(0, pixel.Color(0, spike.slider_pos_r / 2 + 128, 255));
  }

  if (mode == 0) {
    if (spike.slider_touched_l) {
      filter_position = spike.slider_pos_l;
      mf0.setCutoffFreqAndResonance(filter_position, filter_res);
      mf1.setCutoffFreqAndResonance(filter_position, filter_res);
    }
    else if (spike.slider_touched_r) {
      filter_res = spike.slider_pos_r;
      mf0.setCutoffFreqAndResonance(filter_position, filter_res);
      mf1.setCutoffFreqAndResonance(filter_position, filter_res);
    }
  }

  else if (mode == 1) {
    if (spike.slider_touched_l) {
      del_samps = ((spike.slider_pos_l * 8) << 16) + 1;
    }
    else if (spike.slider_touched_r) {
      del_fb = spike.slider_pos_r;
      aDel.setFeedbackLevel((127 - del_fb / 2) + 127);
    }
  }

  else if (mode == 3) {
    if (spike.slider_touched_l) {
      attack = spike.slider_pos_l * 2;
      envelope.setTimes(attack,decay,sustain,release_ms);
      
    }
    else if (spike.slider_touched_r) {
      do_envelope = (spike.slider_pos_r <= 240);
      release_ms = spike.slider_pos_r * 2;
      envelope.setTimes(attack,decay,sustain,release_ms);
    }
    
  }

  else if (mode == 5) {
    if (spike.slider_touched_l) {
      if (spike.slider_pos_l < 128) {spread = spike.slider_pos_l / 32768.0;}
      else {spread = (spike.slider_pos_l - 128) / 2048.0 + 0.00390625;}
    }
    else if (spike.slider_touched_r) {
      oplus = (((int) spike.slider_pos_r / 32) - 2) * 12;
    }
  }

  pixel.show();
}


void doPMChanges(){
  int8_t pm = spike.getPM();
  if (mode == 0) {
    if (base > 12 && pm == -1){
      base -= 12;
    }
    else if (base < 243 && pm == 1) {
      base += 12;
    }
  }
  else if (mode == 5) {base += pm;}
}


void setup() {
  Serial.begin(115200);
  
  spike.begin();
  pixel.begin();
  startMozzi();
  envelope.setLevels(255,255,255,0);
  envelope.setTimes(attack,decay,sustain,release_ms);
  mf0.setCutoffFreqAndResonance(filter_position, filter_res);
  mf1.setCutoffFreqAndResonance(filter_position, filter_res);
}

void loop() {
  audioHook();
}
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

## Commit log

2026-06-29 first release
    [.step, clamp2.3mf, creature.kicad_pcb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]
2026-07-17 filter modes
2026-07-22 Expand README with Spike synthesizer instructions
    Added detailed instructions for building and using the Spike chord synthesizer with Arduino.
